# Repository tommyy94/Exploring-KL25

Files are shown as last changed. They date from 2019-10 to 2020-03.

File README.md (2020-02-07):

# Plantwatch
Takes care of your precious plants.

## Table of contents

- [Description](#description)
- [Hardware](#hardware)

## Description
* Reads soil moisture, temperature and air humidity
* Waters the plant(s) according to soil moisture
* Sends data to remote database via RF link (to be implemented)
* Utilizes low power modes to save energy

## Hardware
* MKL25Z128VLK4
* nRF24L01+ radio module

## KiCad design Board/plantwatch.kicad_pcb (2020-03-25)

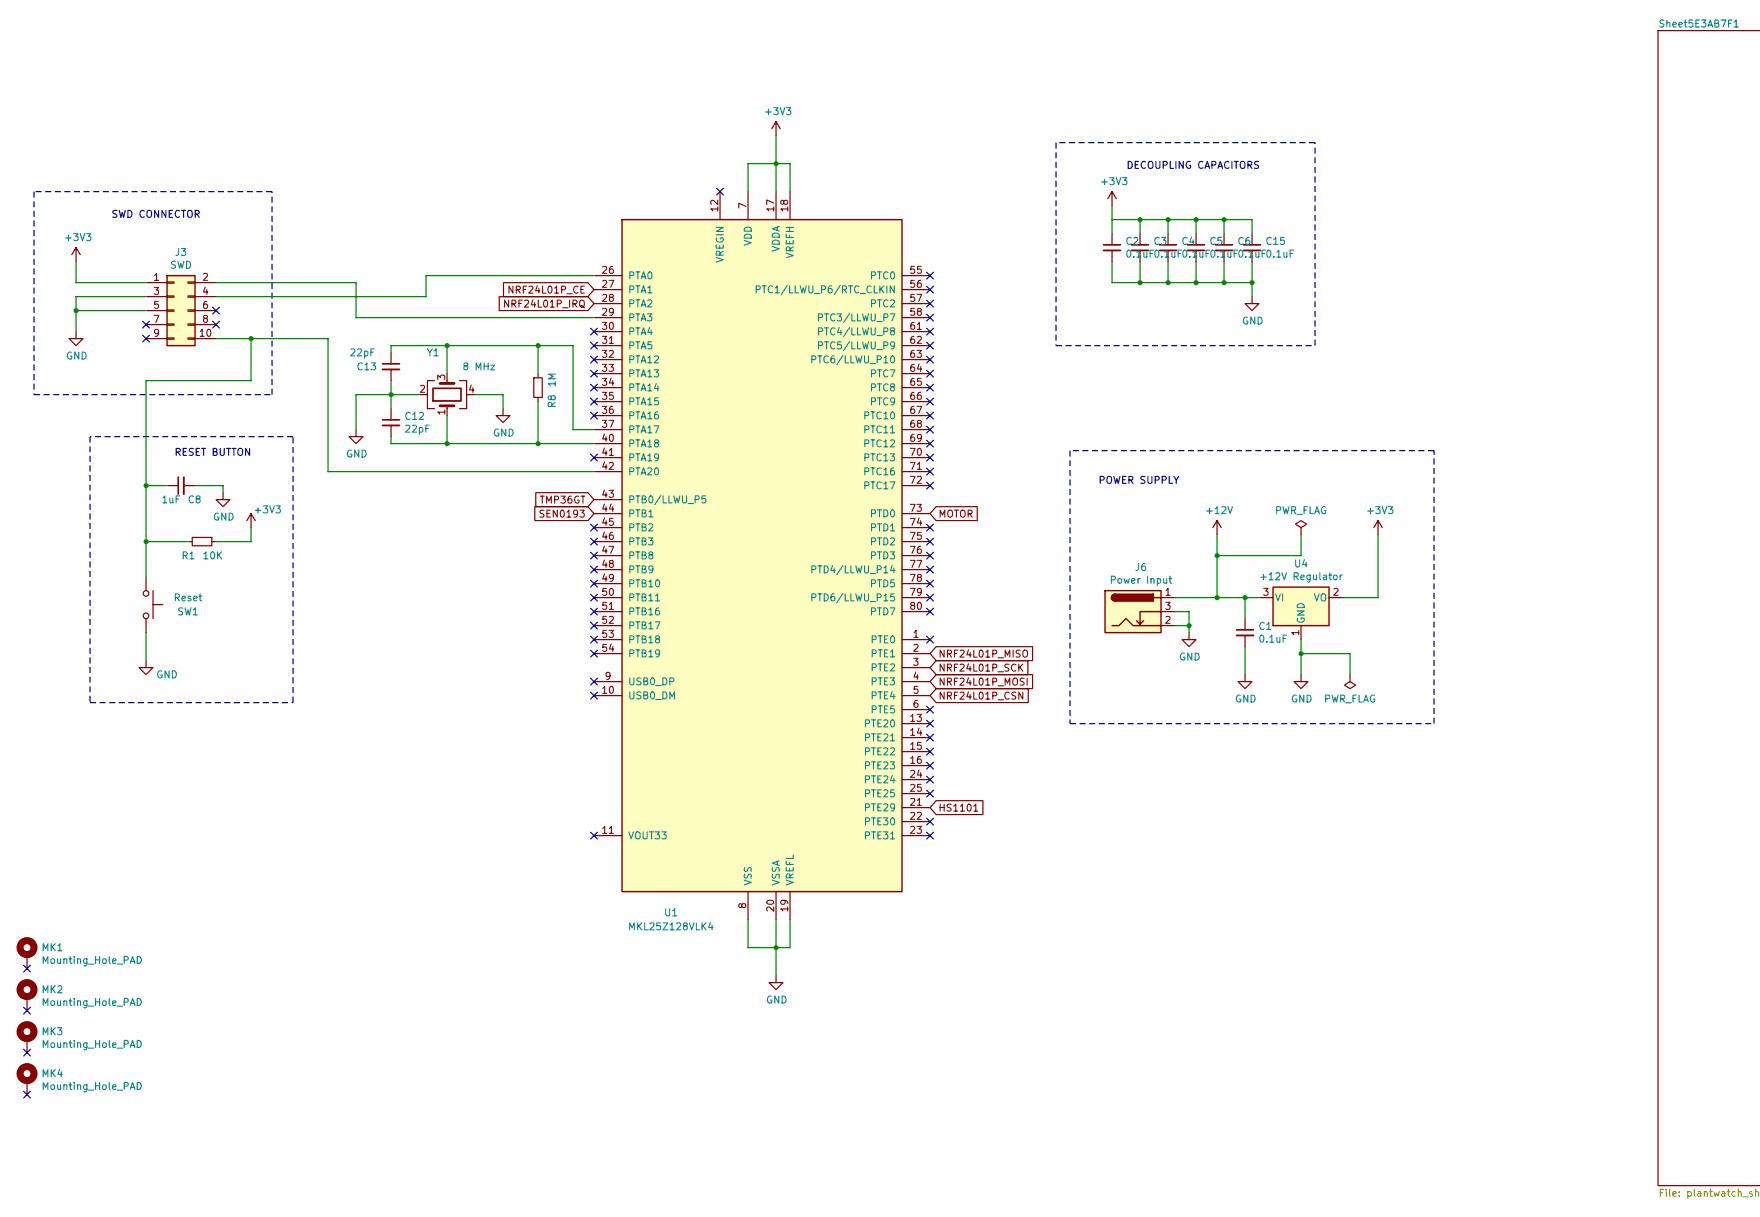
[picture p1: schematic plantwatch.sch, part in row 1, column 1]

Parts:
C1, C2, C3, C4, C5, C6, C15: 0.1uF; CP_EIA-3528-15_AVX-H_Pad1.50x2.35mm_HandSolder
C8: 1uF; CP_EIA-3528-15_AVX-H_Pad1.50x2.35mm_HandSolder
C12, C13: 22pF; CP_EIA-3528-15_AVX-H_Pad1.50x2.35mm_HandSolder
J3: SWD; PinHeader_2x05_P1.27mm_Vertical_SMD
J6: Power Input; BarrelJack_Horizontal
MK1, MK2, MK3, MK4: Mounting_Hole_PAD; MountingHole_2.7mm
R1: 10K; R_2512_6332Metric_Pad1.52x3.35mm_HandSolder
R8: 1M; R_2512_6332Metric_Pad1.52x3.35mm_HandSolder
SW1: Reset; SW_PUSH_6mm
U1: MKL25Z128VLK4; LQFP-80_12x12mm_P0.5mm
U4: +12V Regulator; SOT-223-3_TabPin2
Y1: 8 MHz; Crystal_SMD_0603-4Pin_6.0x3.5mm_HandSoldering

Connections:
+3V3: C2.1, C3.1, C4.1, C5.1, C6.1, C15.1, J3.1, R1.1, U1.7 (VDD), U1.17 (VDDA), U1.18 (VREFH), U1.38 (VDD), U1.60 (VDD), U4.2 (VO); also elsewhere on the board
+12V: C1.1, J6.1, U4.3 (VI); also elsewhere on the board
GND: C1.2, C2.2, C3.2, C4.2, C5.2, C6.2, C8.2, C12.1, C13.2, C15.2, J3.3, J3.5, J6.2, J6.3, SW1.2, U1.8 (VSS), U1.19 (VREFL), U1.20 (VSSA), U1.39 (VSS), U1.59 (VSS), U4.1 (GND), Y1.2, Y1.4; also elsewhere on the board
HS1101: U1.21 (PTE29); also elsewhere on the board
MOTOR: U1.73 (PTD0); also elsewhere on the board
NRF24L01P_CE: U1.27 (PTA1); also elsewhere on the board
NRF24L01P_CSN: U1.5 (PTE4); also elsewhere on the board
NRF24L01P_IRQ: U1.28 (PTA2); also elsewhere on the board
NRF24L01P_MISO: U1.2 (PTE1); also elsewhere on the board
NRF24L01P_MOSI: U1.4 (PTE3); also elsewhere on the board
NRF24L01P_SCK: U1.3 (PTE2); also elsewhere on the board
unnamed: C8.1, J3.10, R1.2, SW1.1, U1.42 (PTA20)
unnamed: C12.2, R8.2, U1.40 (PTA18), Y1.1
unnamed: C13.1, R8.1, U1.37 (PTA17), Y1.3
unnamed: J3.2, U1.29 (PTA3)
unnamed: J3.4, U1.26 (PTA0)
SEN0193: U1.44 (PTB1); also elsewhere on the board
TMP36GT: U1.43 (PTB0/LLWU_P5); also elsewhere on the board

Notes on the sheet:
RESET BUTTON
SWD CONNECTOR
POWER SUPPLY
DECOUPLING CAPACITORS

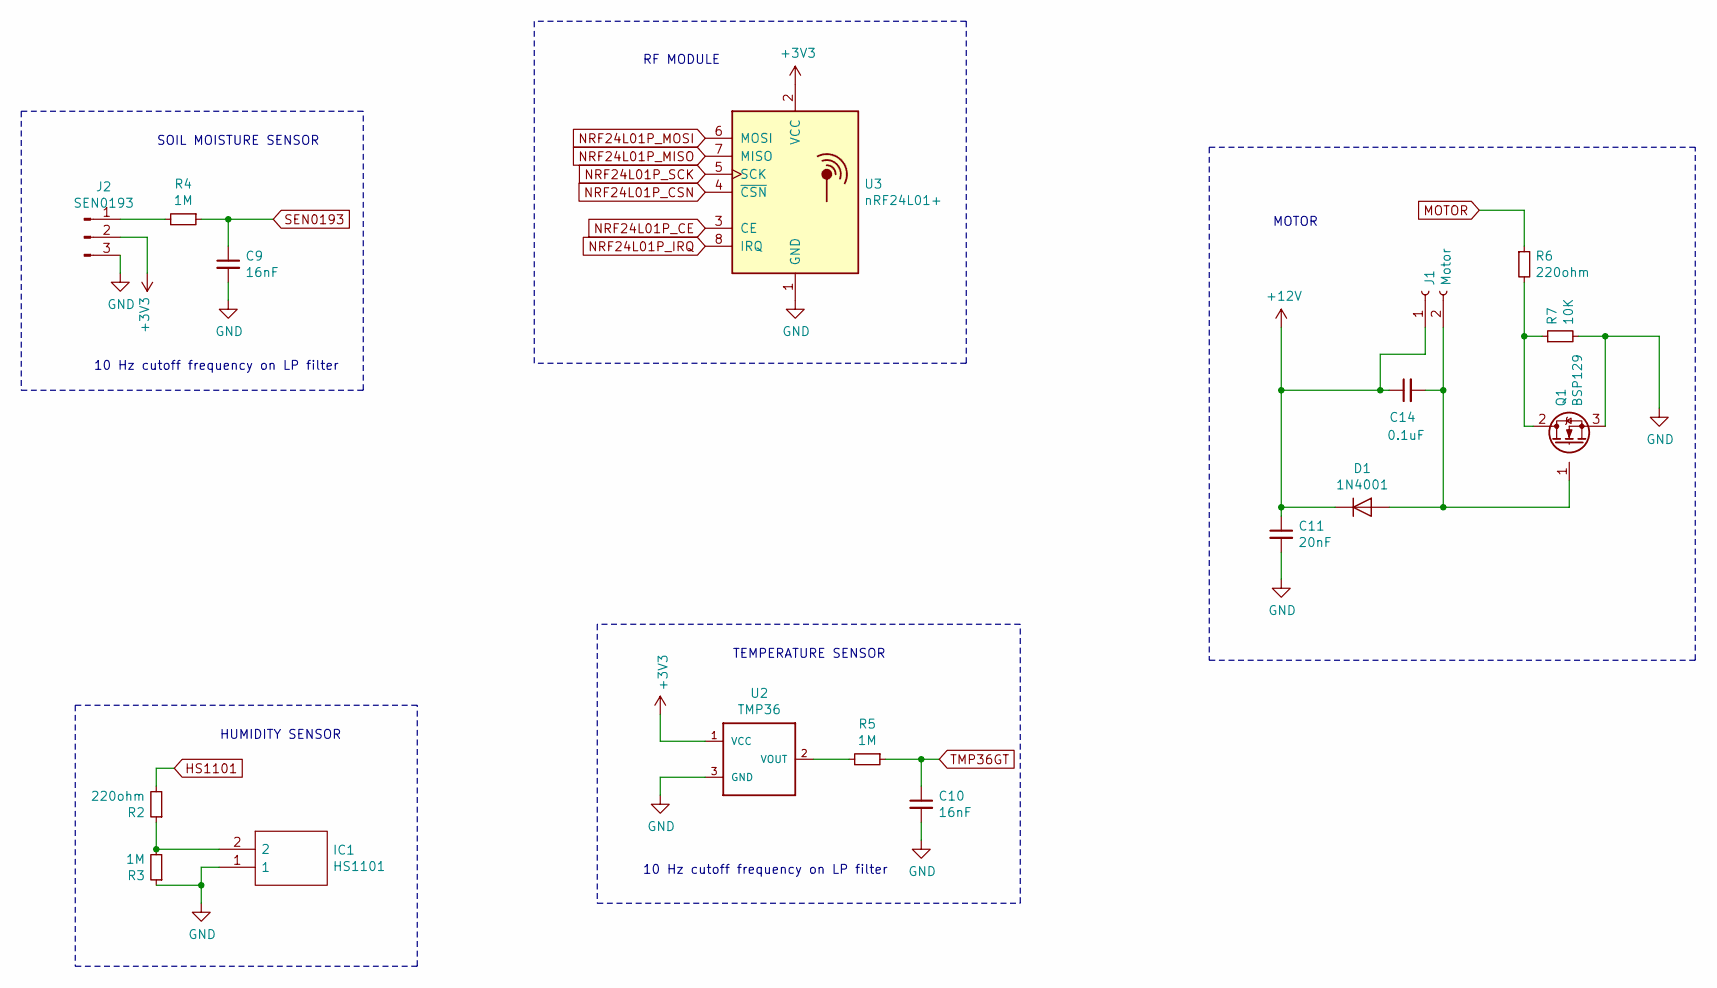
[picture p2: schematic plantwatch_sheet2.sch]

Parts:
C9, C10: 16nF; CP_EIA-3528-15_AVX-H_Pad1.50x2.35mm_HandSolder
C11: 20nF; CP_EIA-3528-15_AVX-H_Pad1.50x2.35mm_HandSolder
C14: 0.1uF; CP_EIA-3528-15_AVX-H_Pad1.50x2.35mm_HandSolder
D1: 1N4001; D_DO-41_SOD81_P10.16mm_Horizontal
IC1: HS1101; HS1101LF; Manufacturer_Part_Number HS1101LF; Mouser Part Number 824-HS1101LF
J1: Motor; PinSocket_2x01_P2.54mm_Vertical
J2: SEN0193; PinSocket_1x03_P2.54mm_Vertical
Q1: BSP129; SOT-223-3_TabPin2
R2, R6: 220ohm; R_2512_6332Metric_Pad1.52x3.35mm_HandSolder
R3, R4, R5: 1M; R_2512_6332Metric_Pad1.52x3.35mm_HandSolder
R7: 10K; R_2512_6332Metric_Pad1.52x3.35mm_HandSolder
U2: TMP36; TO-92
U3: nRF24L01+; nRF24L01_Breakout

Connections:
+3V3: J2.2, U2.1 (VCC), U3.2 (VCC); also elsewhere on the board
+12V: C11.1, C14.1, D1.1 (K), J1.1; also elsewhere on the board
GND: C9.2, C10.2, C11.2, IC1.1, J2.3, Q1.3 (S), R3.1, R7.2, U2.3 (GND), U3.1 (GND); also elsewhere on the board
HS1101: R2.2; also elsewhere on the board
MOTOR: R6.1; also elsewhere on the board
NRF24L01P_CE: U3.3 (CE); also elsewhere on the board
NRF24L01P_CSN: U3.4 (~CSN); also elsewhere on the board
NRF24L01P_IRQ: U3.8 (IRQ); also elsewhere on the board
NRF24L01P_MISO: U3.7 (MISO); also elsewhere on the board
NRF24L01P_MOSI: U3.6 (MOSI); also elsewhere on the board
NRF24L01P_SCK: U3.5 (SCK); also elsewhere on the board
unnamed: C14.2, D1.2 (A), J1.2, Q1.1 (G)
unnamed: IC1.2, R2.1, R3.2
unnamed: J2.1, R4.2
unnamed: Q1.2 (D), R6.2, R7.1
unnamed: R5.2, U2.2 (VOUT)
SEN0193: C9.1, R4.1; also elsewhere on the board
TMP36GT: C10.1, R5.1; also elsewhere on the board

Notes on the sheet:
HUMIDITY SENSOR
10 Hz cutoff frequency on LP filter
TEMPERATURE SENSOR
SOIL MOISTURE SENSOR
MOTOR
RF MODULE

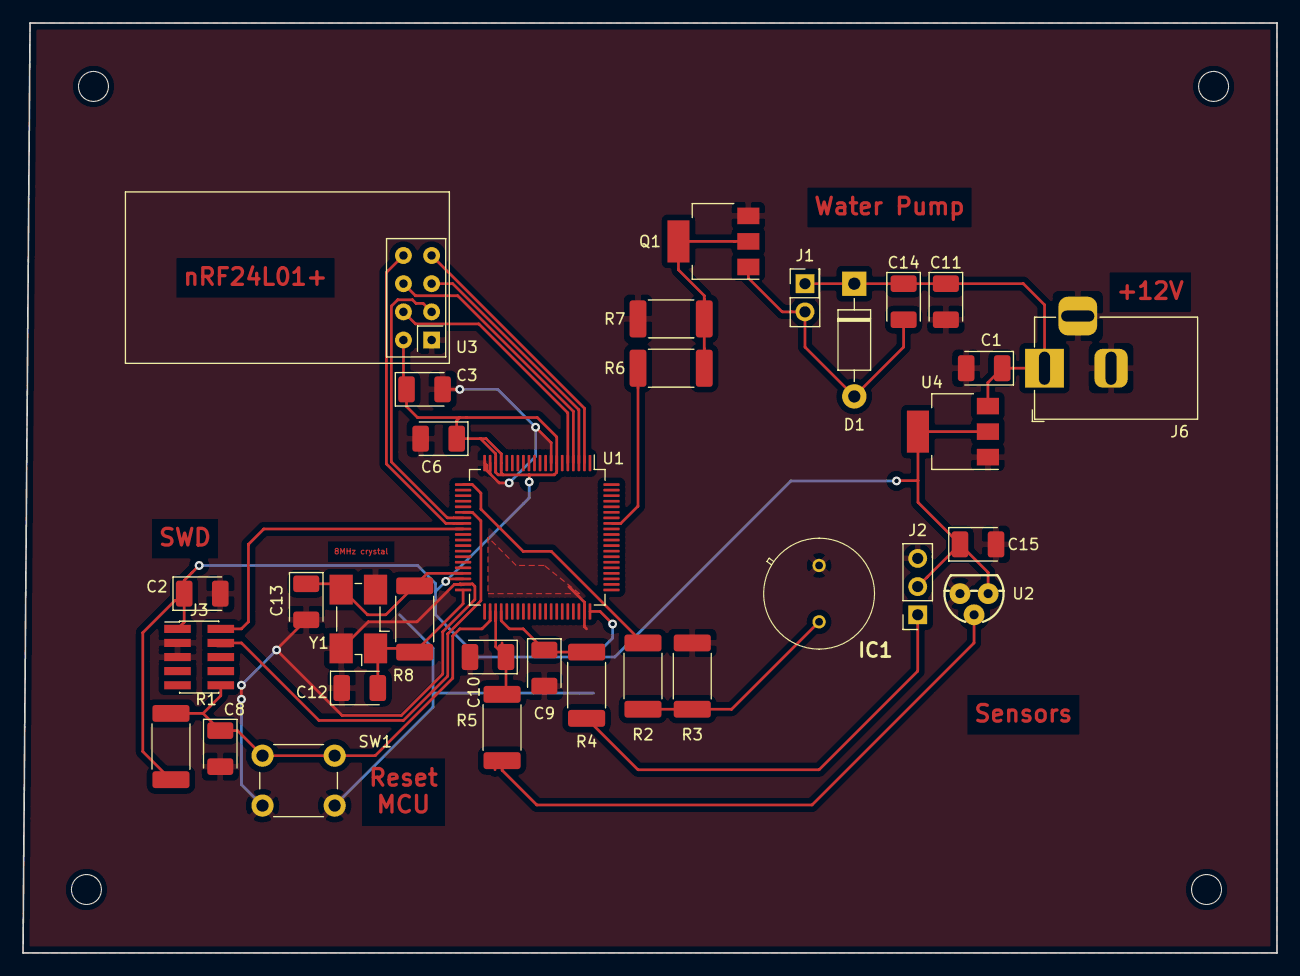
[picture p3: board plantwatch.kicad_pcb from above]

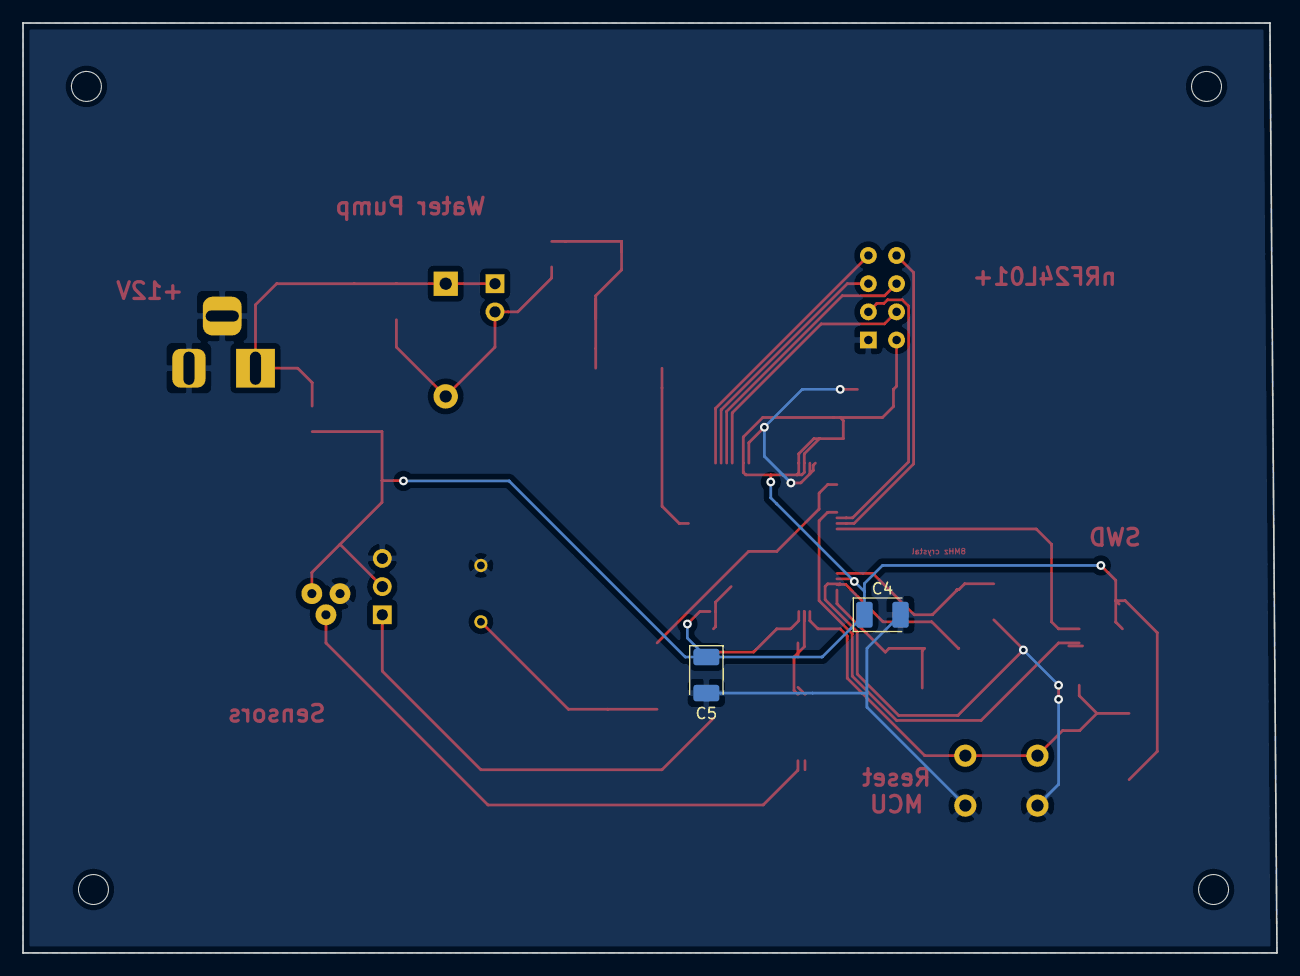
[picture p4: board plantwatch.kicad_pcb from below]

Board: 2 copper layers, 113.0 x 83.8 mm, 39 parts (2 on the bottom side), 23 nets.

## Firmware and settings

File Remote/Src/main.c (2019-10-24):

#include <includes.h>


/**
 * @brief   The main function.
 * 
 * @param   None
 * 
 * @return  None
 */
int main(void)
{
    TaskHandle_t xHandle;
    BaseType_t xAssert;
    static TimerHandle_t xMotorTimers[MOTOR_COUNT];
    
    /* Startup task creates other tasks */
    xAssert = xTaskCreate(vStartupTask, (const char *)"Startup", STARTUPTASKSIZE / sizeof(portSTACK_TYPE), xMotorTimers, STARTUPTASKPRIORITY, &xHandle);
    configASSERT(xAssert);
    
    /* Start multitasking */
    vTaskStartScheduler();
    
    for (;;)
    {
        ; /* Should not get here! */
    }
}

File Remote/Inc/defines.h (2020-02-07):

/**
 * defines.h
 * This header declares global defines.
 */

#pragma once


/* Bit shifting */
#define SIGNAL_SHIFT                    (5) /* For testing purposes */
#define MASK(pin)                       (1UL << (pin))

/* Boolean logic */
#define FALSE                           (0UL)
#define TRUE                            (!FALSE)

/* Signal edges */
#define LOW     (0UL)
#define HIGH    (1UL)

/* Sensor pins */
#define TEMP_SENSOR_PIN                 (0UL)   /* TMP36GT */
#define MOIST_SENSOR_PIN                (1UL)   /* SEN0193 */
#define HUMID_SENSOR_PIN                (29UL)  /* HS1101 */

/* IC Counts */
#define SOIL_MOISTURE_SENSOR_COUNT      (2UL)
#define MOTOR_COUNT                     (1UL)   /* Max 5 */

/* Sensor thresholds */
#define MIN_TEMPERATURE                 (-40L)
#define MAX_TEMPERATURE                 (125L)
#define MAX_HUMIDITY                    (100UL)
#define MAX_SOIL_MOISTURE               (100UL)

/* Sensor formulas */

/**
 * multiplier = 100
 * calibratedSteps = 51000 - 25000
 * moisture = (ADC * multiplier) / calibratedSteps
 * Sensor value is inverted, fix by subtracting ADC from 100
 */
#define SOIL_MOISTURE(adc)              (100 - ((adc) - 25000) * 100 / (51000 - 25000))


/**
 * steps = 2^16 = 0xFFFF
 * Vref = 3300 mV
 * mVout = (Vref / steps) * ADC
 * scaleFactor = 10
 * offsetVoltage = 500 mV
 * TempC = (mVout - offsetVoltage) / scaleFactor
 * Formula is optimized to avoid floating point calculation
 */
#define CELSIUS_TEMPERATURE(adc)        ((((3300 * (adc)) / 0xFFFF) - 500) / 10)


/* Define alternative functions for pins. */
enum AlternativeFunctions
{
    ALT0,
    ALT1,
    ALT2,
    ALT3,
    ALT4,
    ALT5,
    ALT6,
    ALT7,
    RESET
};

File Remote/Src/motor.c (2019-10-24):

/**
 * motor.c
 * This header declares all motor related functions and variables.
 */

#include "motor.h"


/* Local defines*/

/* Global variables */
QueueHandle_t xMotorQueue;
TaskHandle_t xAnalogNotification;


/**
 * @brief   Starts PWM on target channel.
 * 
 * @param   ulChannel       PWM channel
 * @param   pxMotorTimers   Pointer to FreeRTOS software timers.
 * 
 * @return  None
 */
void vStartMotor(const uint32_t ulChannel, TimerHandle_t *const pxMotorTimers)
{
    BaseType_t xAssert;
    
    /* Start software timer */
    xAssert = xTimerStart(pxMotorTimers[ulChannel], (TickType_t)0);
    configASSERT(xAssert);
    
    /* Enable PWM output on channel */
    PORTD->PCR[ulChannel] |= PORT_PCR_MUX(ALT4);
}


/**
 * @brief   Stops PWM on target channel.
 * 
 * @param   ulChannel       PWM channel
 * @param   pxMotorTimers   Pointer to FreeRTOS software timers.
 * 
 * @return  None
 */
void vStopMotor(const uint32_t ulChannel, TimerHandle_t *const pxMotorTimers)
{
    BaseType_t xAssert;
    
    /* Stop software timer */
    xAssert = xTimerStop(pxMotorTimers[ulChannel], (TickType_t)0);
    configASSERT(xAssert);
        
    /* Disable PWM output on channel */
    PORTD->PCR[ulChannel] &= ~PORT_PCR_MUX(ALT4);
}


/**
 * @brief   Drives motors (water pumps) with PWM. PWM is triggered
 *          by boolean values and stopped by setting event bits.
 * 
 * @param   vMotorTimers   Pointer to FreeRTOS software timers.
 * 
 * @return  None
 */
void vMotorTask(void *const pvMotorTimers)
{
    EventBits_t uxBits;
    const TickType_t xTicksToWait = 10 / portTICK_PERIOD_MS;
    struct Motor_States *pxMotors;
    
    for (;;)
    {
        if (xQueueReceive(xMotorQueue, &pxMotors, (TickType_t)10))
        {
            for (uint32_t i = 0; i < MOTOR_COUNT; i++)
            {
                if (pxMotors->ucMotorState[i] == TRUE)
                {
                    vStartMotor(i, (TimerHandle_t *)pvMotorTimers);
                }
            }
        }
        
        uxBits = xEventGroupWaitBits(xMotorEventGroup, 0xF, pdTRUE, pdFALSE, xTicksToWait);
        for (uint32_t i = 0; i < MOTOR_COUNT; i++)
        {
            if (uxBits & (MASK(i) == MASK(i)))
            {
                pxMotors->ucMotorState[i] = FALSE;
                vStopMotor(i, (TimerHandle_t *)pvMotorTimers);
            }
        }
        
        vTaskDelay(pdMS_TO_TICKS(100));
    }
}

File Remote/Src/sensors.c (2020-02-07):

#include "sensors.h"


/* Local defines */


/* Global variables */
QueueHandle_t xAnalogQueue;
QueueHandle_t xMotorQueue;


/* Function descriptions */


/**
 * @brief   FreeRTOS sensor task.
 * 
 * @param   pvParam     Unused.
 * 
 * @return  None
 */
void vSensorTask(void *const pvParam)
{
    (void)pvParam;
    BaseType_t xAssert;
    
    struct Sensor xSensor;
    struct Sensor *pxSensor = &xSensor;

    struct Motor_States xMotors;
    struct Motor_States *pxMotors = &xMotors;
    
    const uint8_t ucSoilMoistureChannels[] = {ADC_CH_AD9, ADC_CH_AD9}; /* Same channel to simulate multiple sensors */
    
    for (;;)
    {
        /* Read all sensor values */
        xSensor.ulPotentiometer = ADC0_usReadPolling(ADC_CH_AD12); /* Not printed */
        
        xSensor.ulHumidity = HS1101_ulReadHumidity();
        //configASSERT(xSensor.ulHumidity <= MAX_HUMIDITY); /* Calibrate sensor first */
        
        xSensor.lTemperature = CELSIUS_TEMPERATURE(ADC0_usReadPolling(ADC_CH_AD8));
        configASSERT(xSensor.lTemperature >= MIN_TEMPERATURE && (xSensor.lTemperature <= MAX_TEMPERATURE));
        
        for (uint8_t i = 0; i < SOIL_MOISTURE_SENSOR_COUNT; i++)
        {
            xSensor.ulSoilMoisture[i] = SOIL_MOISTURE(ADC0_usReadPolling(ucSoilMoistureChannels[i]));
            configASSERT(xSensor.ulSoilMoisture[i] <= MAX_SOIL_MOISTURE);
        }
        
        if (xAnalogQueue != 0)
        {
            xAssert = xQueueSend(xAnalogQueue, (void *)&pxSensor, (TickType_t)10);
            configASSERT(xAssert);
        }
        
        for (uint8_t i = 0; i < SOIL_MOISTURE_SENSOR_COUNT; i++)
        {
            if (xSensor.ulSoilMoisture[i] < SOIL_MOISTURE_THRESHOLD)
            {
                xMotors.ucMotorState[i] = TRUE;
            }
        }
        
        if (xMotorQueue != 0)
        {
            xAssert = xQueueSend(xMotorQueue, (void *)&pxMotors, (TickType_t)10);
            configASSERT(xAssert);
        }
        
        vTaskDelay(pdMS_TO_TICKS(100));
    }
}


/**
 * @brief   TPM1 IRQ Handler used to capture CMP0 output.
 * 
 * @param   None
 * 
 * @return  None
 * @todo    Convert capacitor value (HS1101_ulValue) to humidity.
 */
void TPM1_IRQHandler(void)
{
    BaseType_t xHigherPriorityTaskWoken = pdFALSE;
    static uint32_t ulOverflows = 0;
    uint32_t HS1101_ulValue = 0;
    BaseType_t xAssert;

    if (BME_UBFX32(&TPM1->STATUS, TPM_STATUS_TOF_SHIFT, TPM_STATUS_TOF_WIDTH))
    {
        ulOverflows++;
    }

    if (BME_UBFX32(&TPM1->STATUS, TPM_STATUS_CH1F_SHIFT, TPM_STATUS_CH1F_WIDTH))
    {
        /* Overflows should not happen */
        configASSERT(ulOverflows == 0);

        /* Stop TPM1 */
        BME_AND32(&TPM1->SC, ~TPM_SC_CMOD(1));

        /* Read humidity */
        HS1101_ulValue = TPM1->CONTROLS[1].CnV;

        /* Conversion should have been in progress */
        configASSERT(xAnalogNotification != NULL);

        /* Notify task */
        xAssert = xTaskNotifyFromISR(xAnalogNotification, HS1101_ulValue, eSetValueWithOverwrite, &xHigherPriorityTaskWoken);
        configASSERT(xAssert == pdPASS);

        /* No conversion in progress, so no tasks to notify */
        xAnalogNotification = NULL;

        /* Reset counters */
        TPM1->CNT = 0;
        ulOverflows = 0;
    }

    /* Reset all flags */
    BME_OR32(&TPM1->STATUS, TPM_STATUS_TOF(1) | TPM_STATUS_CH1F(1));
    BME_OR32(&TPM1->CONTROLS[1].CnSC, TPM_CnSC_CHF(1));

    /* Force context switch if xHigherPriorityTaskWoken is set to pdTRUE */
    portEND_SWITCHING_ISR(xHigherPriorityTaskWoken);
}

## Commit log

2018-12-19 DMA triggers only once
2019-03-27 TODO: Fix RF_SetIdleMode() TODO: Implement UART0 RX TODO: Implement CRC
    [analog.c, defines.h, dma.h]
2019-04-08 Fixed CMP0 trigger TMP1 is now measuring CMP0 output correctly TODO: Calibrate humidity sensor
    [analog.c]
2019-04-13 Fixed CMP0 noise issue with extra hysteresis (now properly reads TPM1 IC)
    [HS1101.c, analog.c, defines.h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]
2019-04-19 Calibrated soil moisture sensor
2019-04-22 Restructured main() Built UART frame
2019-04-26 Add UART0 RX
2019-04-28 Build TX frame
2019-05-05 Add hw_timers.*, printf-stdarg.* Fix stackoverflow caused by snprintf() (opting out of stdio.h) Qeues now working
    [analog.c, defines.h, main.c]
2019-05-06 Add Motor task & PWM
2019-05-06 Add FreeRTOS software timers for motor control
2019-05-07 Add events for software timers and motor control
2019-05-08 Fix motor events
2019-05-10 Fix Hard Fault by reorganizing task priorities
    [analog.c, system.c, system.h]
2019-05-10 Fix vSensorTask memory issues
    [HS1101.c, analog.c]
2019-05-11 Add asserts for sensors and software timers
2019-05-17 Add more asserts Can now drive all motors with PWM
2019-06-09 Add BME to HW timers & DMA
2019-06-29 Add TODO
    Implement remote web server
    Create PCB
2019-08-26 SPI transfer now occurs via DMA channel 0
2019-08-29 Remove uart.*
2019-08-30 Move TPM1_IRQHandler from motor.c to sensors.c
2019-08-30 Remove interrupt on complete Add length parameter to DMA0_vInitTransaction()
2019-08-30 TPM2_vLoadCounter() now calculates delay correctly
    [tpm.c]
2019-10-20 Fix nRF24L01 transmission issue
    [nrf24l01.c, spi.c, tpm.c]
2019-10-26 Add working SPI implementation
2020-01-19 Fix HS1101 initialization port
    [adc.c, sensors.c]
2020-01-23 Add KiCad project
    [plantwatch.kicad_pcb, plantwatch.sch, plantwatch_sheet2.sch]
2020-01-24 Make layout
    [plantwatch.kicad_pcb, plantwatch.sch]
2020-02-05 PCB almost done
    [plantwatch.kicad_pcb, plantwatch.sch, plantwatch_sheet2.sch]
2020-02-05 Adding copper pous
    [plantwatch.kicad_pcb]
2020-02-07 PCB done
    [plantwatch.kicad_pcb]
2020-03-25 SWD connector footprint pitch 1.0mm -> 1.27mm
    [plantwatch.kicad_pcb, plantwatch.sch]
